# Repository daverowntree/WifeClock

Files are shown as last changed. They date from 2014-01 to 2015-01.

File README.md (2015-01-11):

# WifeClock
WifeClock project repo

Arduino stack based discrete LED 7-segment display clock with remote control.
Hardware for this first version, is prototyped with veroboard, using VeeCAD for layout and KiCAD for schematic design.

The display unit is modeled in OpenSCAD, and 3D printed on a Prusa i3 reprap.

Right now, I have been unable to find the time to get the radio operating, so the remote control hardware and software will be added to the repo when more complete.  Right now, the remote control is a mere push button on a long pair of wires :)

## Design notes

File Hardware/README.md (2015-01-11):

This folder contains all the hardware files for the project.  
  
Software stack is as follows:  
OpenSCAD, Slic3r, Pronterface (printrun) for 3D printed display unit.  
KiCAD for schematic layout, and VeeCAD for layout (using the netlist generated).  Note: You MUST use the special VeeCAD   libraries for KiCAD.  
  
The realtime clock is based on an external DS1307-based module, which holds a lithium backup battery. You can find these on ebay.

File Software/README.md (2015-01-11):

Software stack consists of the basic Ardunio distribution plus the following libraries:  
DS1307RTC from http://www.pjrc.com/teensy/td_libs_DS1307RTC.html (I think)  
Time  
Wire  
TimerOne from https://code.google.com/p/arduino-timerone/downloads/list  
(VirtualWire) Currently unused  
  
The external libraries are backed up here, in case the internet decides to purge them :D

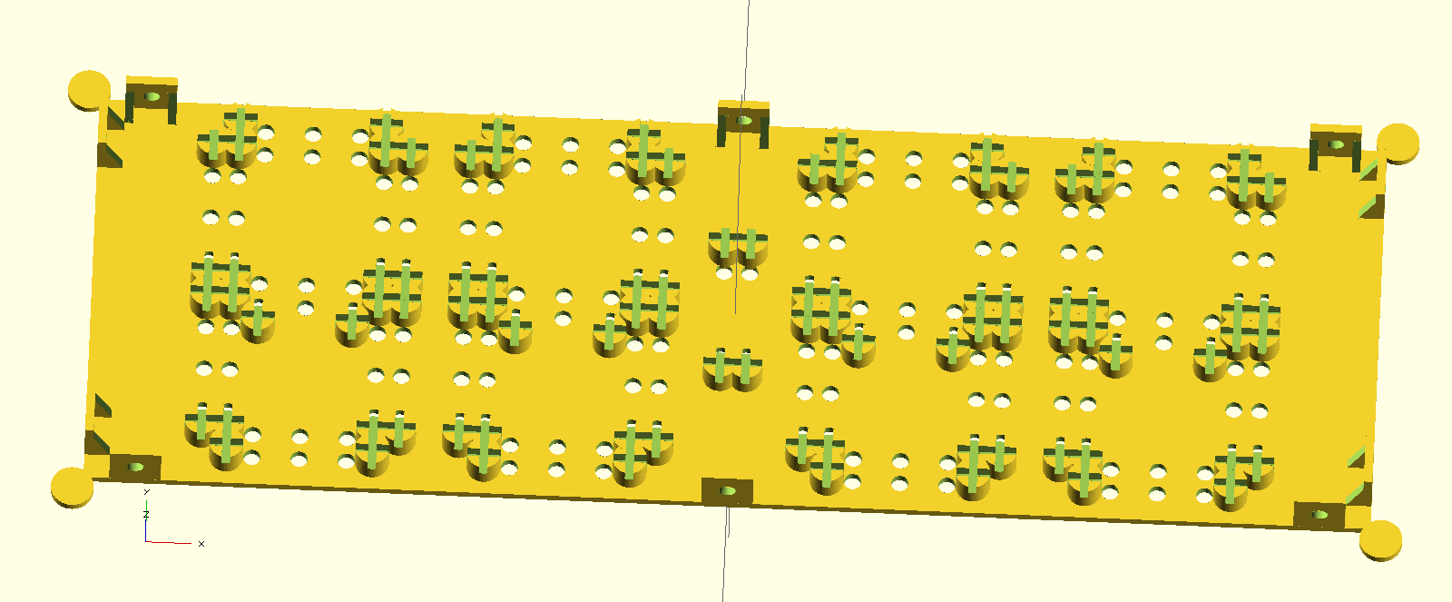
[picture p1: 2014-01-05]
Hardware/display_plate.png

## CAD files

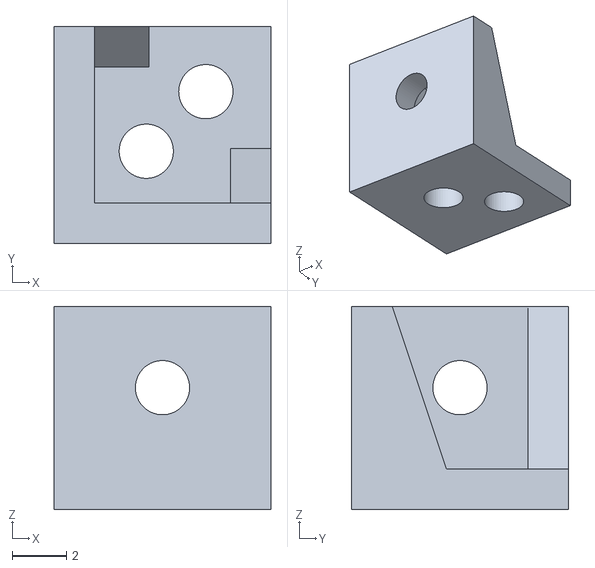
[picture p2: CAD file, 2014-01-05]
Hardware/pcb_mount.stl
8.00 x 8.00 x 7.50

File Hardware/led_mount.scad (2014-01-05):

fineness=50;
plate_thickness = 1;
plate_width = 35*4 + 10;
plate_height = 50;
led_lead_dia = 2;
led_lead_sep = 3;
led_sep = 5.5;
hoz_bar_sep = 20;
vert_bar_sep = 20;
post_height = 4;
post_dia = 4;
post_cutout_width = 1;
post_hoz_sep = 10;
post_vert_sep = 20;
led_dia = 5;
pad_dia=5;
digit_sep=10;

// mounting lugs
lug_height=6;
lug_width=6;
lug_hole_dia=2;
lug_thickness=1;
lug_side_web=2;
lug_top_web=4;
lug_corner_offset=3;

body();

module body() {
plate();
cathode_posts();
anode_posts();
mounting_lugs();

// visualise LEDs
if (0){
led_vis_h();
translate([0,-vert_bar_sep,0]){led_vis_h();}
translate([0,vert_bar_sep,0]){led_vis_h();}

translate([-vert_bar_sep/2,-hoz_bar_sep/2,0]){led_vis_v();}
translate([-vert_bar_sep/2,hoz_bar_sep/2,0]){led_vis_v();}
translate([vert_bar_sep/2,-hoz_bar_sep/2,0]){led_vis_v();}
translate([vert_bar_sep/2,hoz_bar_sep/2,0]){led_vis_v();}
}
}

module mounting_lugs() {
// top and bottom
translate([0,-plate_height/2+lug_thickness/2,lug_height/2+plate_thickness/2]){ rotate([90,0,180]){lug();}}
translate([0,plate_height/2-lug_thickness/2,lug_height/2+plate_thickness/2]){ rotate([90,0,0]){lug();}}

// top left
translate([-plate_width/2+lug_width/2+lug_corner_offset,plate_height/2-lug_thickness/2,lug_height/2+plate_thickness/2]){ rotate([90,0,0]){lug();}}
translate([-plate_width/2+lug_thickness/2,plate_height/2-lug_width/2-lug_corner_offset,lug_height/2+plate_thickness/2]){ rotate([90,0,90]){lug();}}

// top right
translate([plate_width/2-lug_width/2-lug_corner_offset,plate_height/2-lug_thickness/2,lug_height/2+plate_thickness/2]){ rotate([90,0,0]){lug();}}
translate([plate_width/2-lug_thickness/2,plate_height/2-lug_width/2-lug_corner_offset,lug_height/2+plate_thickness/2]){ rotate([90,0,-90]){lug();}}

// bot left
translate([-plate_width/2+lug_width/2+lug_corner_offset,-plate_height/2+lug_thickness/2,lug_height/2+plate_thickness/2]){ rotate([90,0,180]){lug();}}
translate([-plate_width/2+lug_thickness/2,-plate_height/2+lug_width/2+lug_corner_offset,lug_height/2+plate_thickness/2]){ rotate([90,0,90]){lug();}}

// bot right
translate([plate_width/2-lug_width/2-lug_corner_offset,-plate_height/2+lug_thickness/2,lug_height/2+plate_thickness/2]){ rotate([90,0,180]){lug();}}
translate([plate_width/2-lug_thickness/2,-plate_height/2+lug_width/2+lug_corner_offset,lug_height/2+plate_thickness/2]){ rotate([90,0,-90]){lug();}}

}

module lug(rotate=0) {
difference(){
cube (size = [lug_width,lug_height,lug_thickness], center = true);
translate([0,0,-2]){cylinder(h=2+lug_thickness,r=lug_hole_dia/2,$fn=fineness);}
}

// webbing
translate([-lug_width/2+lug_thickness/2,-lug_height/2+lug_top_web/2,lug_thickness/2+lug_side_web/2]) {support_web();}
translate([lug_width/2-lug_thickness/2,-lug_height/2+lug_top_web/2,lug_thickness/2+lug_side_web/2]) {support_web();}
}

module support_web(){
diag=sqrt(pow(2,lug_top_web)+pow(2,lug_side_web));
rot=atan(lug_side_web/lug_top_web);
difference(){
cube (size = [lug_thickness,lug_top_web,lug_side_web], center=true);
translate([0,lug_top_web/2,-lug_side_web/2]){ // 0,0,0 lug_thickness/2,lug_top_web/2,0
  rotate(a=[-rot,0,0]){
    translate([0,-lug_top_web/2,lug_side_web/2]){ // 0,0,0 -lug_thickness/2,-lug_top_web/2,0
       translate([0.1,(-diag+lug_top_web)/2,0]){
        cube (size = [lug_thickness+0.5,diag,lug_side_web], center=true);
      }
    }
  }
}
}
}

module cathode_posts() {
// Four digits
translate([-vert_bar_sep*3/2-digit_sep*2,0,0]){cathode_posts_single();}
translate([-vert_bar_sep/2-digit_sep,0,0]){cathode_posts_single();}
translate([vert_bar_sep*3/2+digit_sep*2,0,0]){cathode_posts_single();}
translate([vert_bar_sep/2+digit_sep,0,0]){cathode_posts_single();}

// and a pair of separators
translate([-led_lead_sep/2,-led_sep*3/2,0]){corner_post();}
translate([-led_lead_sep/2,led_sep*3/2,0]){corner_post();}

}

module anode_posts() {
// Four digits
translate([-vert_bar_sep*3/2-digit_sep*2,0,0]){anode_posts_single();}
translate([-vert_bar_sep/2-digit_sep,0,0]){anode_posts_single();}
translate([vert_bar_sep*3/2+digit_sep*2,0,0]){anode_posts_single();}
translate([vert_bar_sep/2+digit_sep,0,0]){anode_posts_single();}

// and a pair of separators
translate([led_lead_sep/2,-led_sep*3/2,0]){corner_post();}
translate([led_lead_sep/2,led_sep*3/2,0]){corner_post();}
}

module cathode_posts_single() {
color(""){
//bottom
translate([-post_hoz_sep+led_lead_sep/2,-post_vert_sep+led_lead_sep/2,0]){corner_post(rotate=0);}
translate([post_hoz_sep-led_lead_sep/2,-post_vert_sep+led_lead_sep/2,0]){corner_post(rotate=0);}

//middle
translate([-post_hoz_sep+led_lead_sep/2,+led_lead_sep/2,0]){corner_post(rotate=0);}
translate([post_hoz_sep-led_lead_sep/2,+led_lead_sep/2,0]){corner_post(rotate=0);}
translate([-post_hoz_sep+led_lead_sep/2,-led_lead_sep/2,0]){corner_post(rotate=0);}
translate([post_hoz_sep-led_lead_sep/2,-led_lead_sep/2,0]){corner_post(rotate=0);}

//top
translate([-post_hoz_sep+led_lead_sep/2,post_vert_sep-led_lead_sep/2,0]){corner_post(rotate=0);}
translate([post_hoz_sep-led_lead_sep/2,post_vert_sep-led_lead_sep/2,0]){corner_post(rotate=0);}
}
}

module anode_posts_single() {

//bottom
color(""){
translate([-post_hoz_sep+led_lead_sep/2,-post_vert_sep-led_lead_sep/2,0]){corner_post(rotate=0);}
translate([post_hoz_sep-led_lead_sep/2,-post_vert_sep-led_lead_sep/2,0]){corner_post(rotate=0);}
translate([-post_hoz_sep-led_lead_sep/2,-post_vert_sep+led_lead_sep/2,0]){corner_post(rotate=0);}
translate([post_hoz_sep+led_lead_sep/2,-post_vert_sep+led_lead_sep/2,0]){corner_post(rotate=0);}
}
//middle

translate([-led_sep,-vert_bar_sep/2+led_sep,0]){corner_post(rotate=0);}
translate([led_sep,-vert_bar_sep/2+led_sep,0]){corner_post(rotate=0);}
translate([-post_hoz_sep-led_lead_sep/2,-led_lead_sep/2,0]){corner_post(rotate=0);}
translate([post_hoz_sep+led_lead_sep/2,-led_lead_sep/2,0]){corner_post(rotate=0);}

translate([-post_hoz_sep-led_lead_sep/2,led_lead_sep/2,0]){corner_post(rotate=0);}
translate([post_hoz_sep+led_lead_sep/2,led_lead_sep/2,0]){corner_post(rotate=0);}

//top
translate([-post_hoz_sep+led_lead_sep/2,post_vert_sep+led_lead_sep/2,0]){corner_post(rotate=0);}
translate([post_hoz_sep-led_lead_sep/2,post_vert_sep+led_lead_sep/2,0]){corner_post(rotate=0);}
color(""){
translate([-post_hoz_sep-led_lead_sep/2,post_vert_sep-led_lead_sep/2,0]){corner_post(rotate=0);}
translate([post_hoz_sep+led_lead_sep/2,post_vert_sep-led_lead_sep/2,0]){corner_post(rotate=0);}
}
}

module plate() {
difference() {
cube (size = [plate_width,plate_height,plate_thickness], center = true);
// Four digits
translate([-vert_bar_sep*3/2-digit_sep*2,0,0]){led_holes();}
translate([-vert_bar_sep/2-digit_sep,0,0]){led_holes();}
translate([vert_bar_sep*3/2+digit_sep*2,0,0]){led_holes();}
translate([vert_bar_sep/2+digit_sep,0,0]){led_holes();}

// and a pair of separators
translate([0,-led_sep,0]){led_hole_h();}
translate([0,led_sep,0]){led_hole_h();}
}

// corner pads
translate([-plate_width/2-pad_dia/4,-plate_height/2-pad_dia/4,-plate_thickness/2]){cylinder (h=plate_thickness,r=pad_dia/2,$fn=fineness);}
translate([-plate_width/2-pad_dia/4,plate_height/2+pad_dia/4,-plate_thickness/2]){cylinder (h=plate_thickness,r=pad_dia/2,$fn=fineness);}
translate([plate_width/2+pad_dia/4,-plate_height/2-pad_dia/4,-plate_thickness/2]){cylinder (h=plate_thickness,r=pad_dia/2,$fn=fineness);}
translate([plate_width/2+pad_dia/4,plate_height/2+pad_dia/4,-plate_thickness/2]){cylinder (h=plate_thickness,r=pad_dia/2,$fn=fineness);}
}

module led_holes(){
translate([0,-hoz_bar_sep,0]){hoz_bar();}
translate([0,0,0]){hoz_bar();}
translate([0,hoz_bar_sep,0]){hoz_bar();}
translate([-vert_bar_sep/2,-hoz_bar_sep/2,0]){vert_bar();}
translate([-vert_bar_sep/2,hoz_bar_sep/2,0]){vert_bar();}
translate([vert_bar_sep/2,-hoz_bar_sep/2,0]){vert_bar();}
translate([vert_bar_sep/2,hoz_bar_sep/2,0]){vert_bar();}

}

module hoz_bar(){
led_hole_v();
translate([-led_sep,0,0]){led_hole_v();}
translate([led_sep,0,0]){led_hole_v();}
}

module led_vis_h() {
color("blue", 0.5){
translate ([0,0,-4]){cylinder(h=5,r=led_dia/2,$fn=fineness);}
translate ([-led_sep,0,-4]){cylinder(h=5,r=led_dia/2,$fn=fineness);}
translate ([led_sep,0,-4]){cylinder(h=5,r=led_dia/2,$fn=fineness);}
}
}

module vert_bar(){
led_hole_h();
translate([0,-led_sep,0]){led_hole_h();}
translate([0,led_sep,0]){led_hole_h();}
}

module led_vis_v() {
color("blue", 0.5){
translate ([0,0,-4]){cylinder(h=5,r=led_dia/2,$fn=fineness);}
translate ([0,-led_sep,-4]){cylinder(h=5,r=led_dia/2,$fn=fineness);}
translate ([0,led_sep,-4]){cylinder(h=5,r=led_dia/2,$fn=fineness);}
}
}

module led_hole_v() {
translate ([0,-led_lead_sep/2,-2]){cylinder(h=5,r=led_lead_dia/2,$fn=fineness);}
translate ([0,led_lead_sep/2,-2]){cylinder(r=led_lead_dia/2,h=5,$fn=fineness);}
}


module led_hole_h() {
translate ([-led_lead_sep/2,0,-2]){cylinder(h=5,r=led_lead_dia/2,$fn=fineness);}
translate ([led_lead_sep/2,0,-2]){cylinder(r=led_lead_dia/2,h=5,$fn=fineness);}
}
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

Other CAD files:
Hardware/pcb_mount.scad

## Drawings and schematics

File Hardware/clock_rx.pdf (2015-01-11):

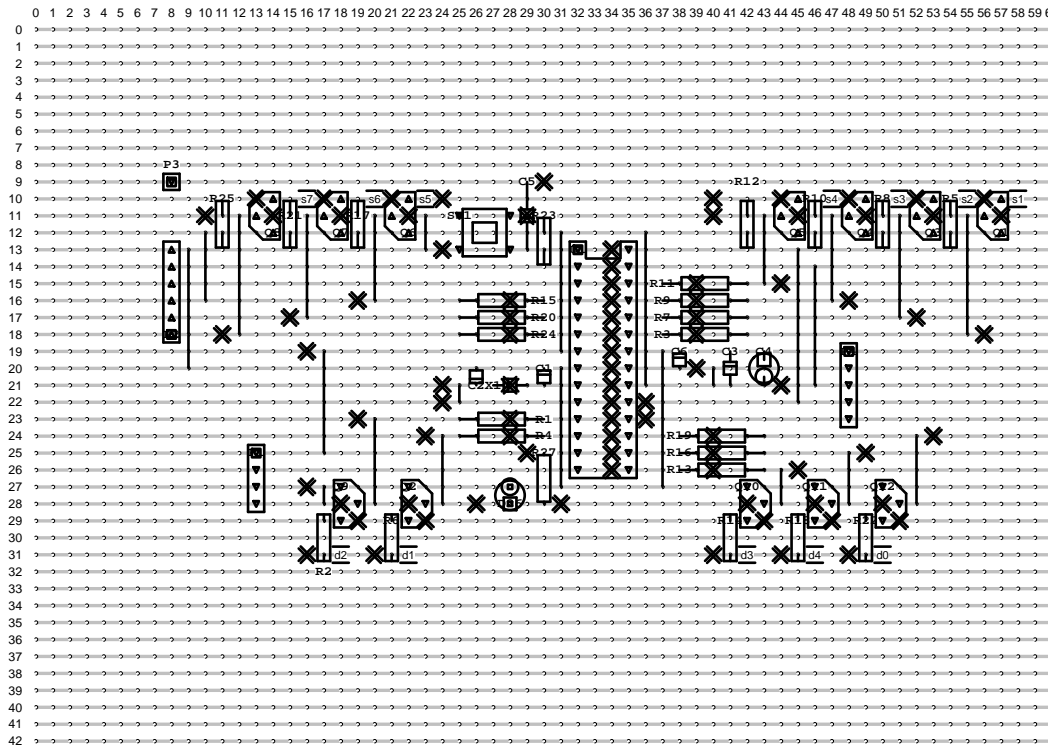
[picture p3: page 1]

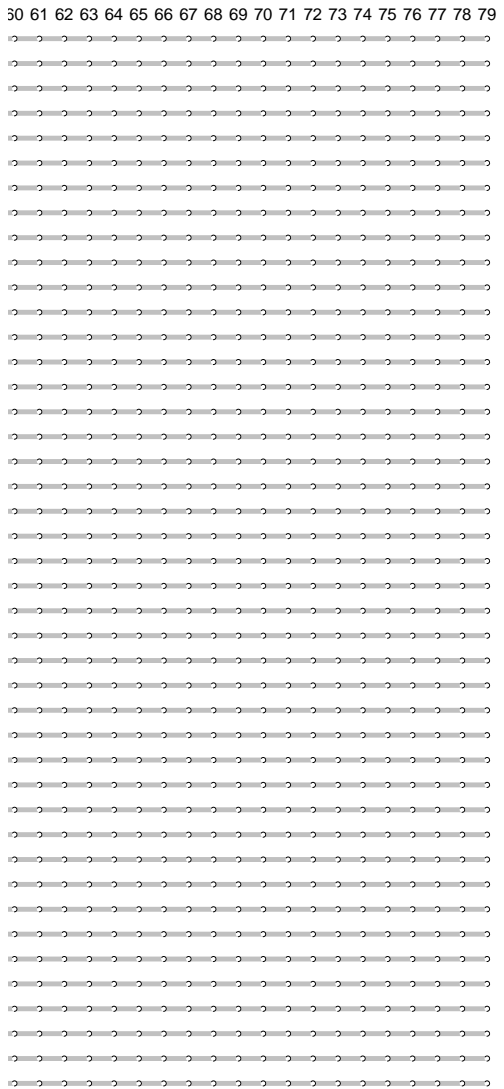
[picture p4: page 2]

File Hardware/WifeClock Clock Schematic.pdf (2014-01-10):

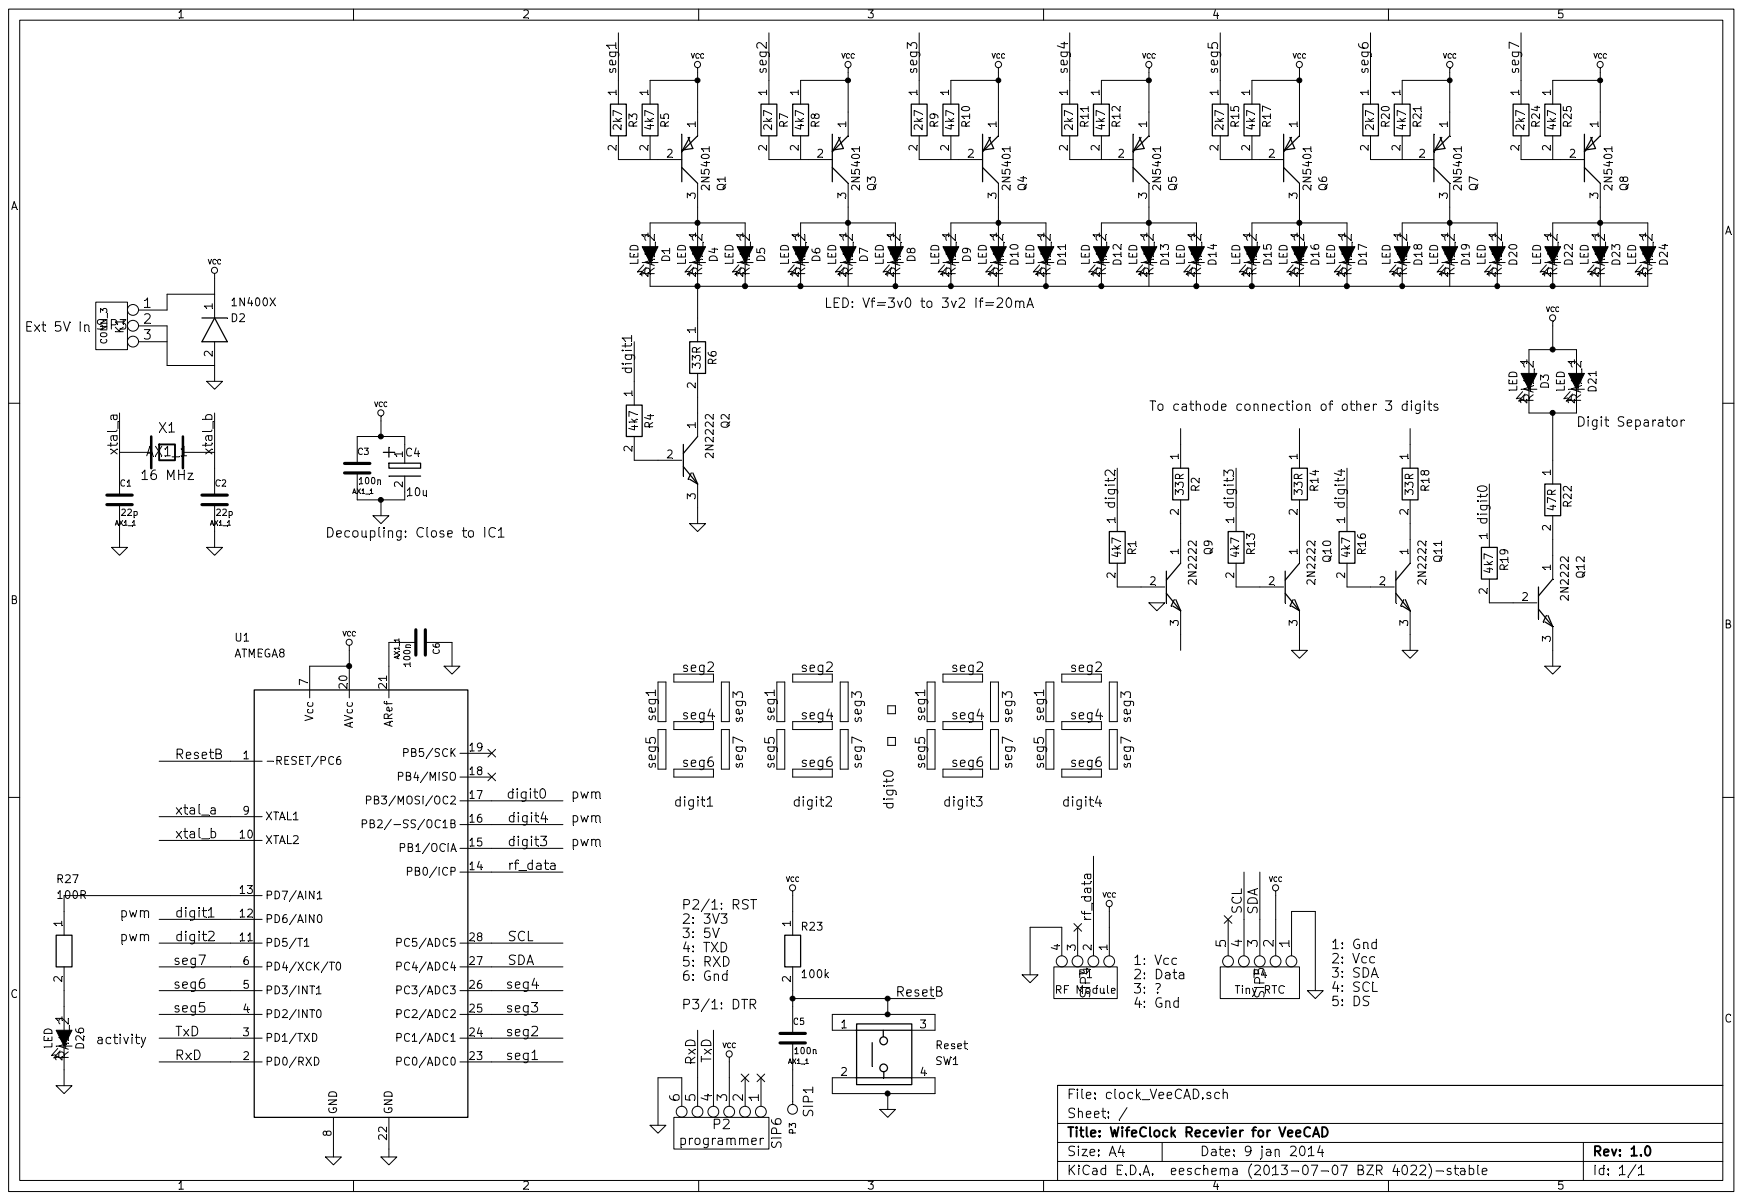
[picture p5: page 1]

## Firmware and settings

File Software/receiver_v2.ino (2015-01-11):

/*
  WifeClock Receiver (the clock bit) for Arduino.1.0.5

  Set Board->Arduino Uno
  Set Progammer->AVRISP MkII (others untested)

  Dave Rowntree
  
  Version  Date        Notes
  1.0      19/01/14    Initial version
  1.1      
  
*/
#include "Arduino.h"
#include <DS1307RTC.h>
#include <Time.h>
#include <Wire.h>

#include <TimerOne.h>
//#include <VirtualWire.h>

#include "radio.h"
#include "constants.h"
#include "setup.h"
#include "clock_core.h"
#include "display.h"
#include "globals.h"

// Port globals
// Need to store the current values of the digital ports in one common place, and combine the
// bits from all connections in one place 

char PortB = 0;
char PortC = 0;
char PortD = 0;

int slot = 0;
boolean TOS_flag = false;
boolean TOS_enable = false;
boolean DIG_SEP_reset_flag = false;
boolean DIG_SEP_enable = false;
boolean DIG_SEP_flag = false;

state_t State = HOLD;

// hardware mappings
const int digits[NUM_DIGITS] = {DIG0_PIN,DIG1_PIN,DIG2_PIN,DIG3_PIN,DIG4_PIN}; // digital pin number so we can use digitalWrite
char dig1=0, dig2=0, dig3=0, dig4=0;
char blank_dig[NUM_DIGITS] = {0,0,0,0};

// Digit lookup table; convert ascii to segment pattern - we need two patterns, one for portC and portD
// need to avoid PD[7..5] as these are used for digits and activity LED
// index[0] is ascii(32)

/*
        s2              s1 pc0
     xxxxxxxx           s2 pc1
  s1 x      x s3        s3 pc2
     x  s4  x           s4 pc3
     xxxxxxxx           s5 pd2
  s5 x      x s7        s6 pd3
     x      x           s7 pd4
     xxxxxxxx
        s6
*/

// Just digits 0-9 for now
// Other potential digits that can be represented: A b cC d eE F G H I J L n oO P Q r S t uU Y
const char lookup_tab_pc[] = {0b00000111, 0b00000001, 0b00001110, 0b00001110, 0b00001101, 0b00001101, 0b00001101, 0b00000110, 0b00001111, 0b00001111};
const char lookup_tab_pd[] = {0b00011100, 0b00000100, 0b00001100, 0b00011000, 0b00010000, 0b00011000, 0b00011100, 0b00010000, 0b00011100, 0b00011000};

//char gMode = DISPLAY_12HR;
char gMode = DISPLAY_24HR;
char scan_phase = 0;

// main application loop
void loop() {
#ifndef PLAN_B
    uint8_t buf[VW_MAX_MESSAGE_LEN];
    uint8_t buflen = VW_MAX_MESSAGE_LEN;

    // rf_loop kicks off the clock 'loop' for a fixed time then get's restarted
    if (vw_get_message(buf, &buflen)){ // Non-blocking
        Serial.println("HERE");
        checkmessage(buf);
    }
#endif
    clock_loop();
}

bool checkmessage(uint8_t *buf){
  
    Serial.print("rx:");  
    Serial.println((char*)buf);  
    
    return(true); // fixme
}

char seconds_counter = 0;

void clock_loop(){
    char tick_flag = 1;
    char tick_counter = 10; // 10 seconds
    char dig = 0;
    char sep = 0;      
#ifdef PLAN_B    
    pinMode(RF_IN_PIN, INPUT);
    digitalWrite(RF_IN_PIN, HIGH);
   
    if (!digitalRead(RF_IN_PIN)){
      seconds_counter = 10;
     Serial.println("push!"); 
    }
#endif    

    //while(1){
      if (seconds_counter){
	if (TOS_flag && TOS_enable) {
	    time_to_digits(&dig1, &dig2, &dig3, &dig4);
	    digitalWrite(DIG0_PIN, HIGH);  
	}    
	if (DIG_SEP_reset_flag && DIG_SEP_enable){
	    digitalWrite(DIG0_PIN, LOW); 
	    DIG_SEP_reset_flag = false;
	}
      } else {
	    digitalWrite(DIG0_PIN, LOW); 
	    DIG_SEP_reset_flag = false;        
      }
      
	if (slot==0){
	    if (tick_flag){
		tick_counter--;
		//Serial.println("tick!"); 
		tick_flag = 0;

#ifdef PLAN_B
              if (seconds_counter){
                seconds_counter--;    
              }
#endif
	    }
	}
    
	if (slot>900){
	    tick_flag = 1; 
	}
	//if (!tick_counter) return;
    //}
}

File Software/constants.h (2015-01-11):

// constant declarations

// Hardware Consts
#define NUM_SEGMENTS 70
#define NUM_DIGITS 5
#define ACT_LED 7
#define RF_IN_PIN 8

// Global config defaults
#define MAX_BRIGHTNESS 255
//      BRIGHTNESS units/ms
#define FADEIN_RATE 10
#define FADEOUT_RATE 10

//      ms
#define WAKE_TIME 5000

// 12/24 Hour mode
#define DISPLAY_12HR 0
#define DISPLAY_24HR 1

// ->Main state machine<-
typedef enum {IDLE, SLEEP, FADEIN, HOLD, FADEOUT } state_t;

// digital bindings
// PortB
// 0 rf_data
// 1 digit3
// 2 digit4
// 3 digit0
// 4 x
// 5 x
// 6 x
// 7 x

// Masks and shifts
#define PORTB_DIG_MASK 0x0e
#define PORTB_DIG_SHIFT 1
#define PORTB_RFIN_MASK 0x01
#define PORTB_RFIN_SHIFT 0

// Hardware pin mapping
#define DIG3_PIN  9
#define DIG4_PIN  10
#define DIG0_PIN  11

// PortC
// 0 seg1
// 1 seg2
// 2 seg3
// 3 seg4
// 4 (SDA)
// 5 (SCL)
// 6 x
// 7 x

// Masks and shifts
#define PORTC_SEG_MASK 0x1f
#define PORTC_SEG_SHIFT 0

// Hardware pin mapping
#define SEG1_PIN 14
#define SEG2_PIN 15
#define SEG3_PIN 16
#define SEG4_PIN 17
#define SDA_PIN 27
#define SCL_PIN 28

// PortD
// 0 RxD
// 1 TxD
// 2 seg5
// 3 seg6
// 4 seg7
// 5 digit2
// 6 digit1
// 7 activity

// Masks and shifts
#define PORTD_SEG_MASK 0x1c
#define PORTD_SEG_SHIFT 2
#define PORTD_DIG_MASK 0x60
#define PORTD_DIG_SHIFT 5
#define PORTD_ACT_MASK 0x80
#define PORTD_ACT_SHIFT 7

// Hardware pin mapping
#define RXD_PIN 2
#define TXD_PIN 3
#define SEG5_PIN 2
#define SEG6_PIN 3
#define SEG7_PIN 4
#define DIG2_PIN 5
#define DIG1_PIN 6

// Maximum number of bytes in a message, counting the byte count and FCS
#define VW_MAX_MESSAGE_LEN 30

// The maximum payload length
#define VW_MAX_PAYLOAD VW_MAX_MESSAGE_LEN-3

// The size of the receiver ramp. Ramp wraps modulu this number
#define VW_RX_RAMP_LEN 160

// Number of samples per bit
#define VW_RX_SAMPLES_PER_BIT 8

// Ramp adjustment parameters
// Standard is if a transition occurs before VW_RAMP_TRANSITION (80) in the ramp,
// the ramp is retarded by adding VW_RAMP_INC_RETARD (11)
// else by adding VW_RAMP_INC_ADVANCE (29)
// If there is no transition it is adjusted by VW_RAMP_INC (20)
#define VW_RAMP_INC (VW_RX_RAMP_LEN/VW_RX_SAMPLES_PER_BIT)
#define VW_RAMP_TRANSITION VW_RX_RAMP_LEN/2
#define VW_RAMP_ADJUST 9
#define VW_RAMP_INC_RETARD (VW_RAMP_INC-VW_RAMP_ADJUST)
#define VW_RAMP_INC_ADVANCE (VW_RAMP_INC+VW_RAMP_ADJUST)

// Outgoing message bits grouped as 6-bit words
// 36 alternating 1/0 bits, followed by 12 bits of start symbol
// Followed immediately by the 4-6 bit encoded byte count, 
// message buffer and 2 byte FCS
// Each byte from the byte count on is translated into 2x6-bit words
// Caution, each symbol is transmitted LSBit first, 
// but each byte is transmitted high nybble first
#define VW_HEADER_LEN 8

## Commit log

2014-01-05 Initial checkin
    [led_mount.scad, led_mount.stl]
2014-01-10 Added schematic of receiver
    [clock_VeeCAD.sch]
2015-01-11 Project update for deployment
    Moved hardware stuff into it's own subfolder and uploaded initial stab
    at software
    [clock_VeeCAD.sch, led_mount.scad, pcb_mount.scad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]
2015-01-11 Commit backup of non-standard Arduino libraries needed
